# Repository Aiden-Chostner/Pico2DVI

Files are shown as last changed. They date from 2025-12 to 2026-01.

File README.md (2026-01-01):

# Pico2DVI
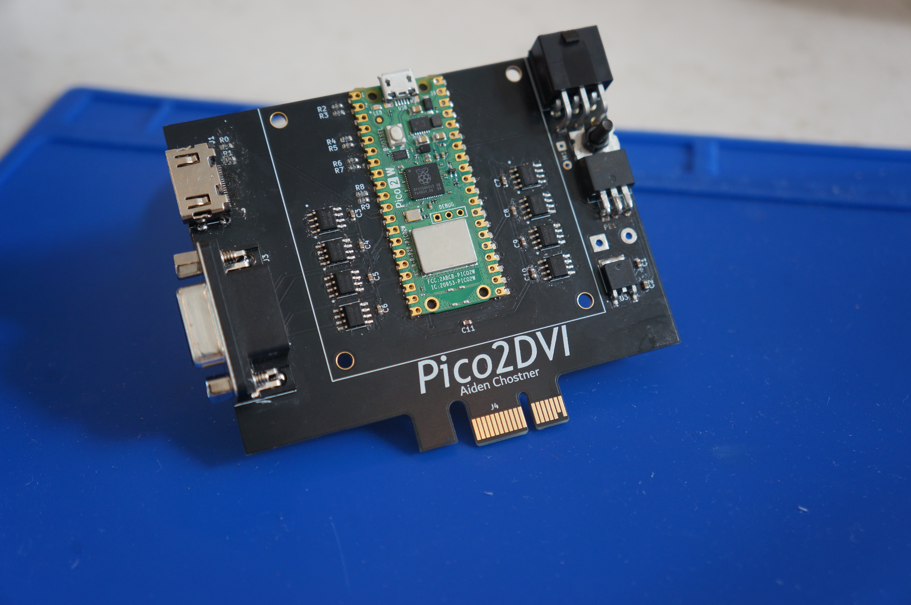
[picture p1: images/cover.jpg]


## Story
Recently, I began exploring circuit design, and I liked the idea of creating my own custom graphics card because it sounded like a fun project. After some back and forth of choosing requirements for the GPU, I settled on using a Raspberry Pi Pico as the main processor. It already had a graphics library made for it, which would make adding HDMI support simple. I saw [PicoDVI by Luke Wren](https://github.com/Wren6991/PicoDVI), but I wanted to add more RAM and some extra capabilities. I added 32MB of VRAM (Video Random Access Memory), which is about 250 times less capacity and 36 million times slower than the memory on a modern GPU. (As you can probably tell, I was not going for speed.) The Pico also has Wi-Fi and extra general-purpose pins. That means the card can take in user inputs like a keyboard and output data in ways other than just a display. It can also fetch data (e.g stock market information) from the Internet. I prioritized versatility over speed.

## Specs
* RP2350 Core
* 32 MB VRAM
* HDMI DVI
* Extra I/O
* Subzero Cooler
* Wifi 2.4 GHz

## If you want to build it, I have an [instructables page](https://www.instructables.com/Pico2DVI-the-Graphics-Card-You-Can-Build-Yourself/)!

## Schematic
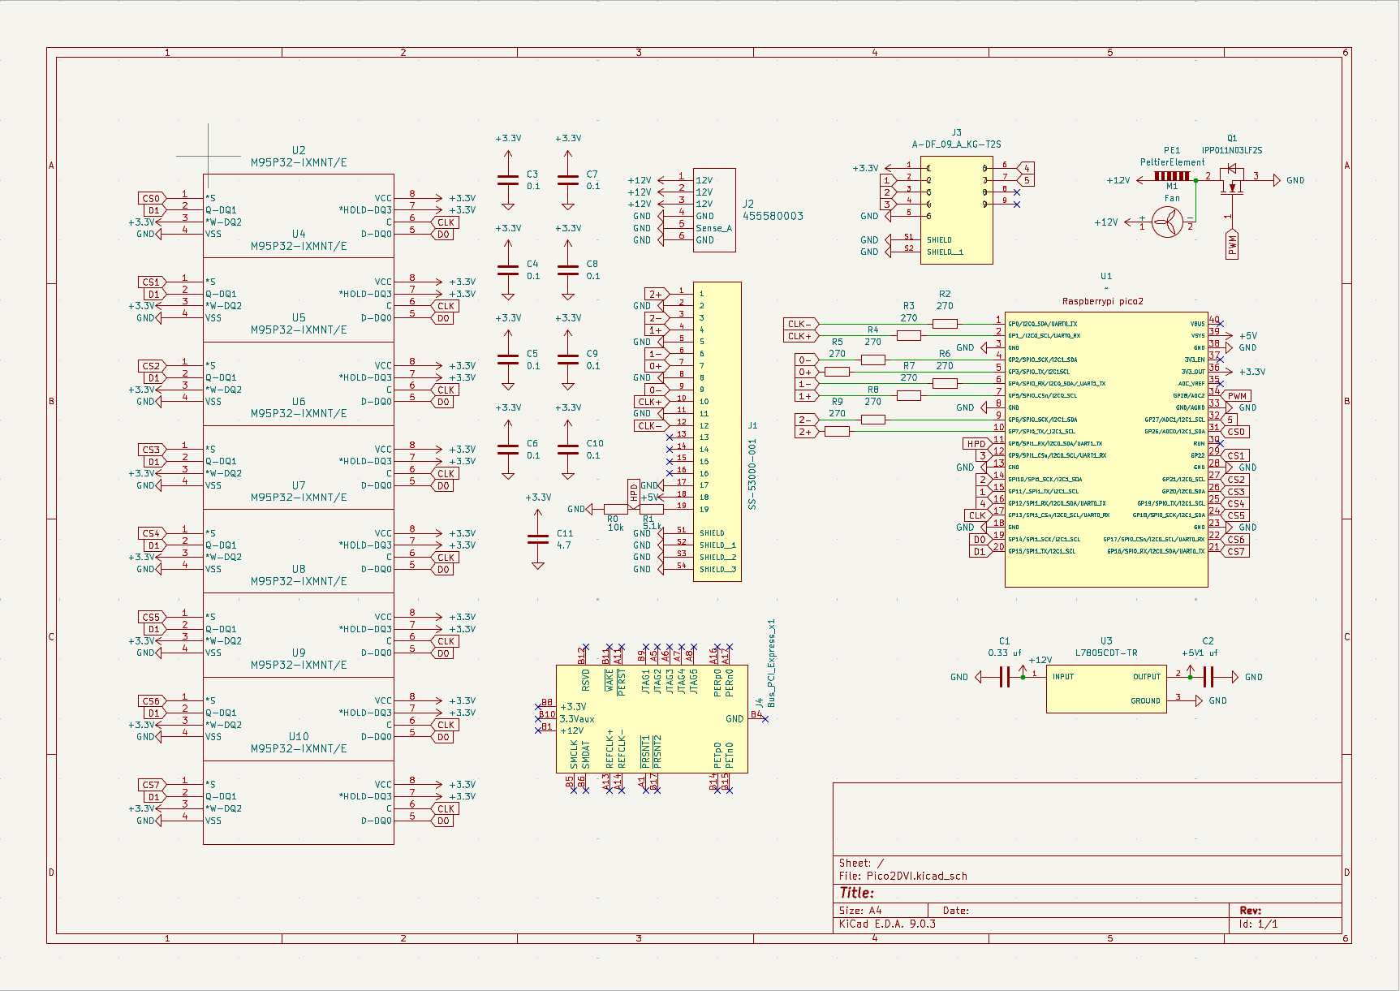
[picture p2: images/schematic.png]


### I went through a couple variations changing:
* Memory
* Cooling
* Extra I/O Pins

## PCB
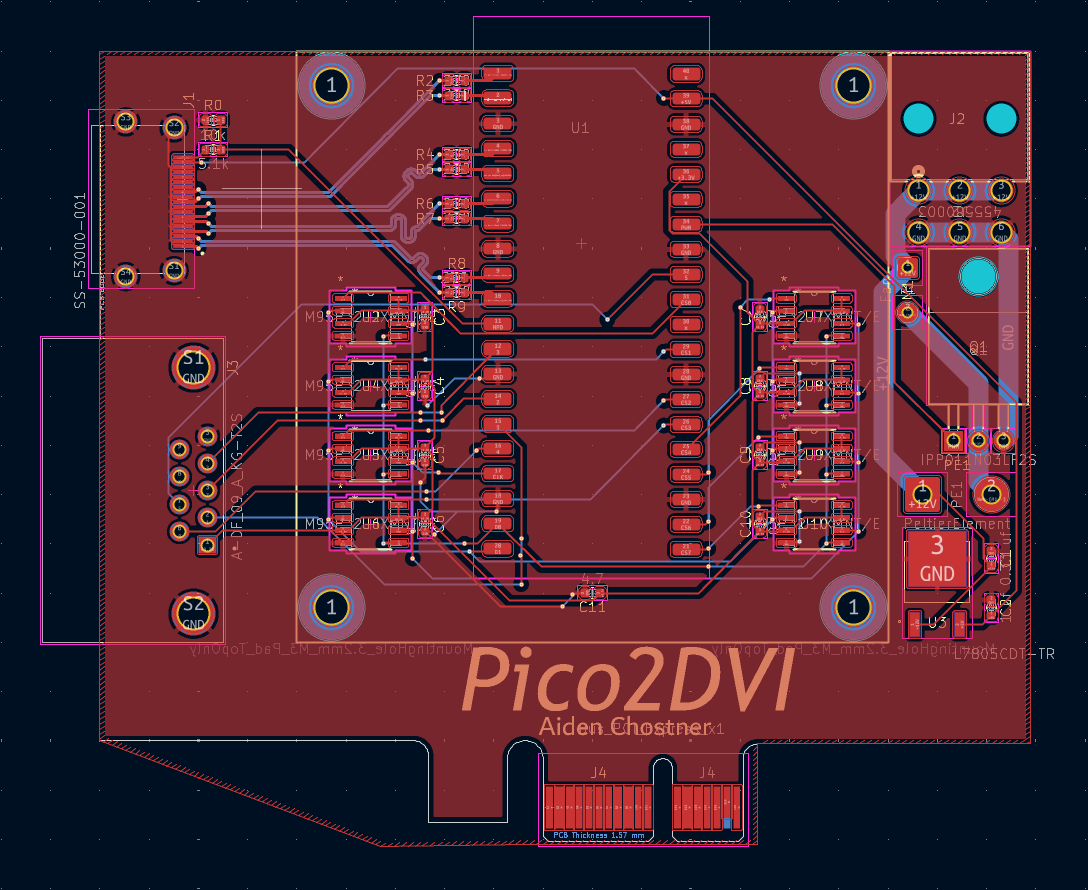
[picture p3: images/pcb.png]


### Impedance 
The hardest part about designing the PCB was getting the DVI traces correct. At the clock speeds that DVI runs at, electricity starts to behave unpredictably. The signals start to degrade to the point where they cannot be properly received by the monitor. To correct the signals, I needed to use the impedance calculator in KiCad. It took a couple of attempts through trial and error to correctly calculate the impedance needed for DVI.

## Subzero Cooler
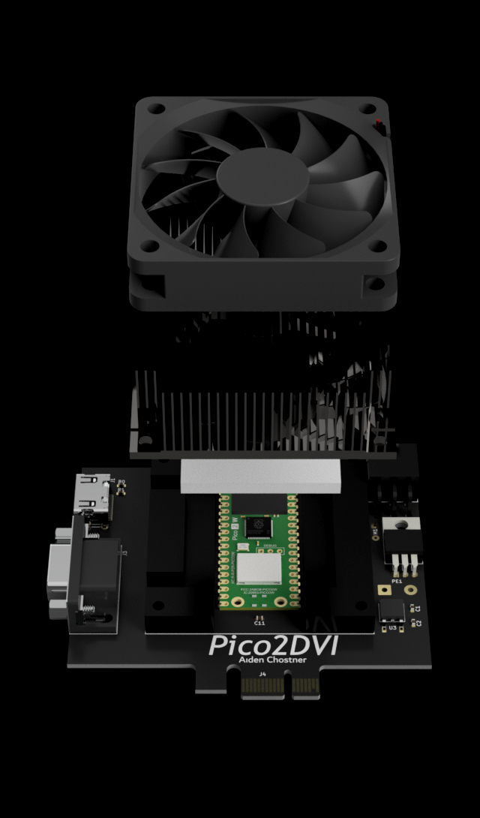
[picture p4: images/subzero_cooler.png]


### Peltier Module
For HDMI to work properly the Raspberry Pi needs to be overclocked. This generates excess heat so I designed a subzero cooler. It uses a Peltier module which uses electricity to move heat from one side to the other. Using one on the GPU allows the core temperature to be lower than the room it is in.

## Memory
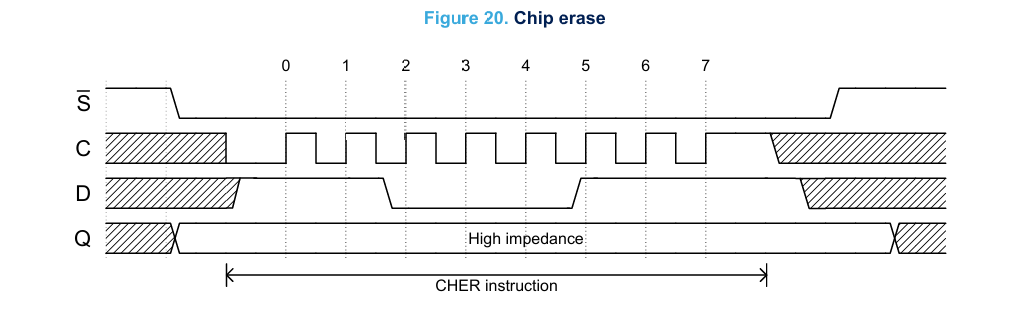
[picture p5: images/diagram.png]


### Bitbanging
The protocol the memory chips use is called SPI. (Serial Peripheral Interface) Each chip uses four wires on a shared bus with every other chip, which saves valuable GPIO pins from the Raspberry Pi. I decided to bitbang the signals and code them manually. Each instruction, like reading or writing, has a different timing diagram like the one above. I made a function that had modular instructions so I did not have to manually code each one.

# Projects!
## Hello World
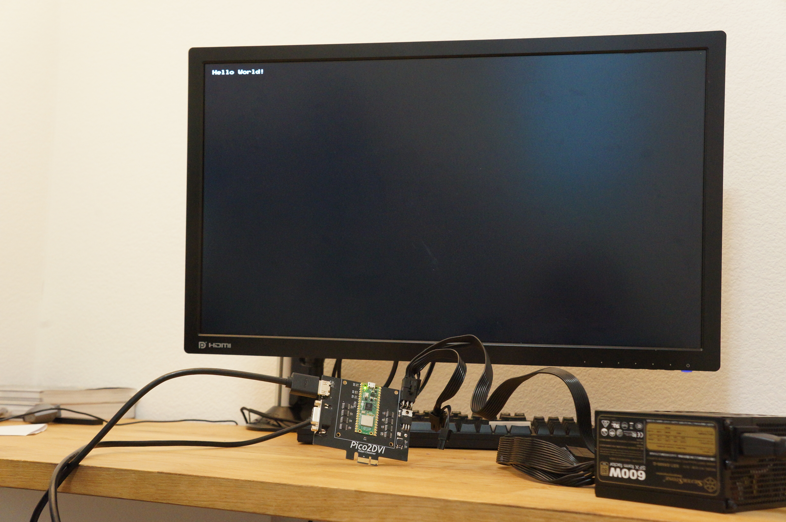
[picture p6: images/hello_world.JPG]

When I first got the graphics card working I was so excited. It took four revisions to get the circuit board design right. The months of designing and building finally paid off!

Then, I started work on making a frame to build off of. I first started to work on controlling the cooler. It uses a feedback loop so it can idle at a set temperature. It can even go below zero! Next, I added a overlay that shows all the data of the graphics card, including FPS, clock speed, and more. I also made a simple render script so that the card can display pixels instead of just plain text.

## Conway's Game of Life
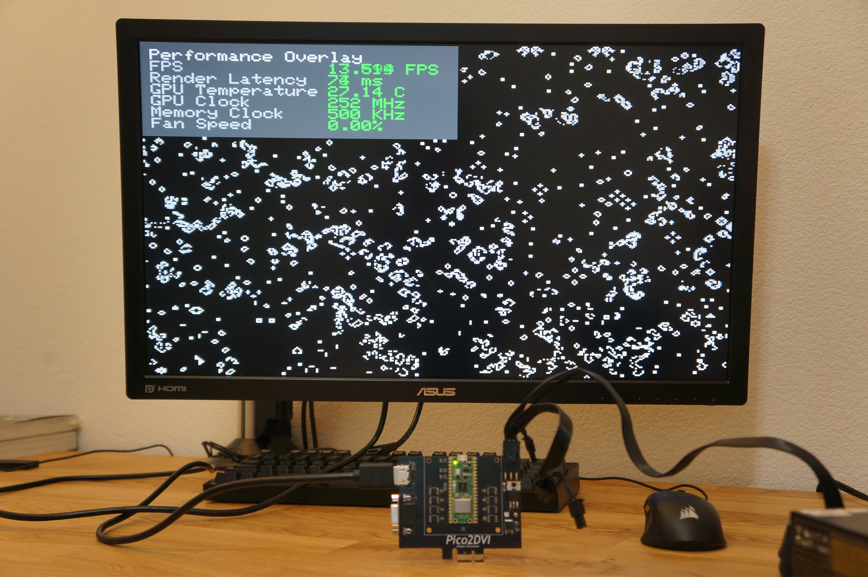
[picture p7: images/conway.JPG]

Conway's Game of Life is a zero player game where there is a grid with cells. Each cell can either be alive or dead. The eight pixels around a cell are called its neighbors. If there are less than two neighbors, that cell will die. If there are two or three neighbors around a live cell, then it will move on to the next generation. If there are more than three neighbors, it will die. If there are exactly three cells around a dead cell, it becomes alive. These four simple rules create a complex system.

To make the game, I used two screen buffers. One buffer to render to the screen and in the background, I would use the second one to calculate the next generation. Each pixel needs to know its neighbors around it, so I created an indexing system. Each pixel has its own index which I add or subtract a certain value to get the position of the pixels around it. Using the position, it checks whether or not the cell is alive.

## Future
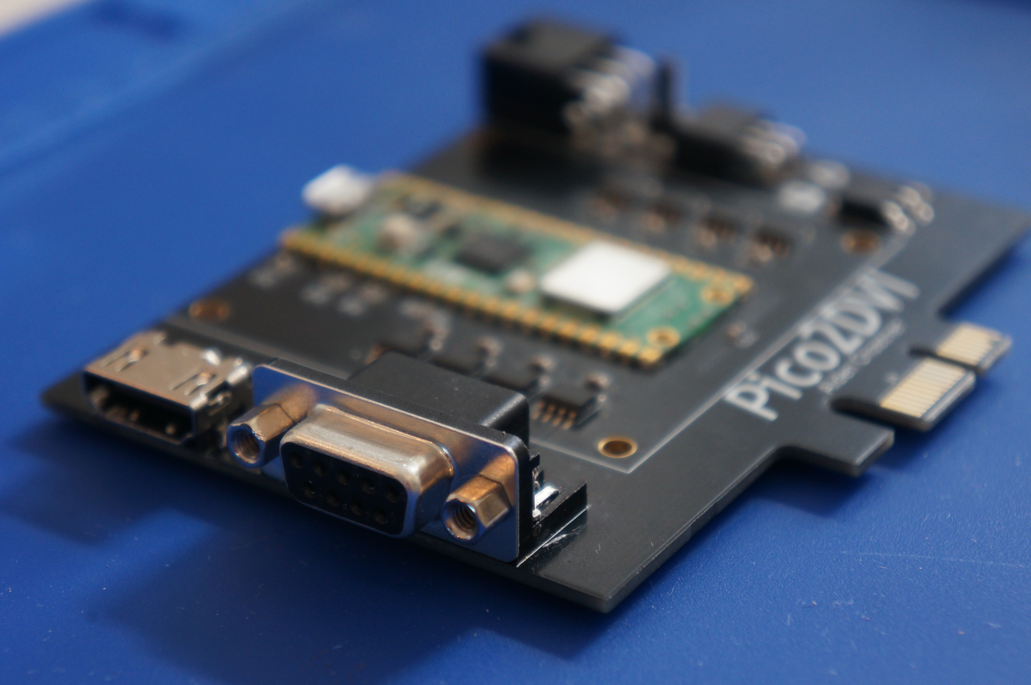
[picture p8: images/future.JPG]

In the future, I want to expand this project by making a couple games like Tetris or maybe Doom. I think a simple raytracing engine would be cool. I have tried making a simple engine in [Shadertoy](https://shadertoy.com) and it was pretty fun. I could even use the memory to make a neural network!

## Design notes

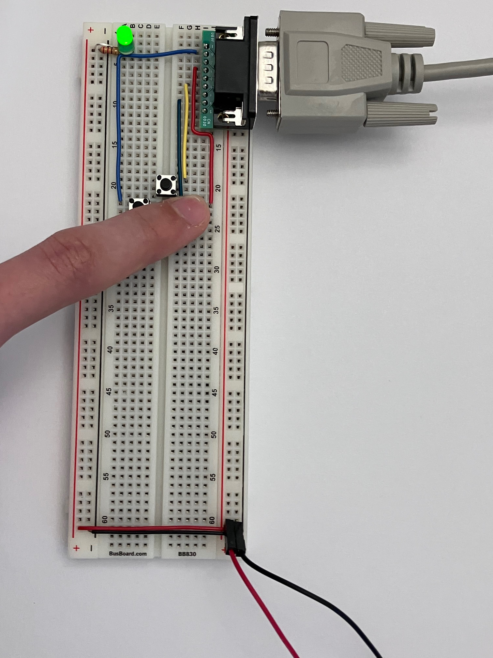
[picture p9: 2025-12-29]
images/buttons.jpg

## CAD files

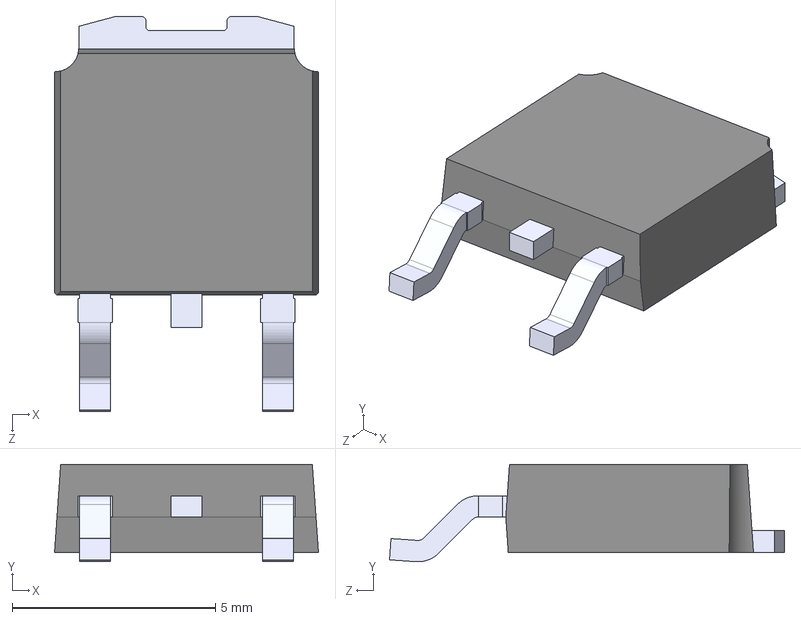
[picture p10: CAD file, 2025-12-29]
KiCad/Footprints/5V/L7805CDT-TR.step
6.50 x 2.40 x 9.72 mm

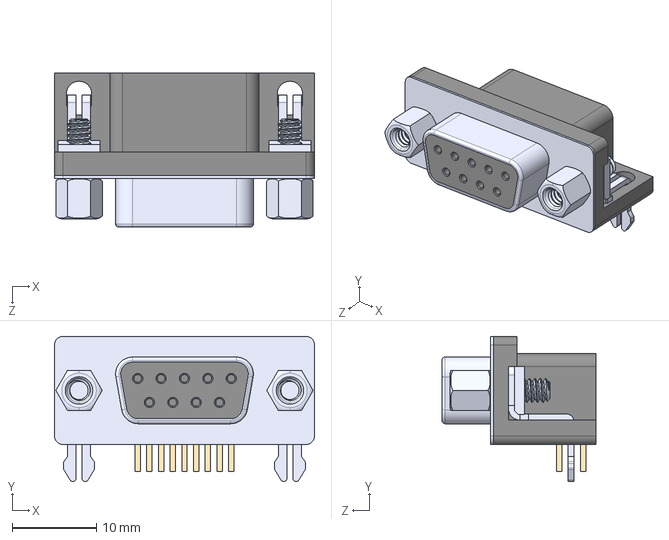
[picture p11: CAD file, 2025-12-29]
KiCad/Footprints/Dsub 9/A-DF_09_A_KG-T2S.step
30.8 x 17.2 x 18.3 mm

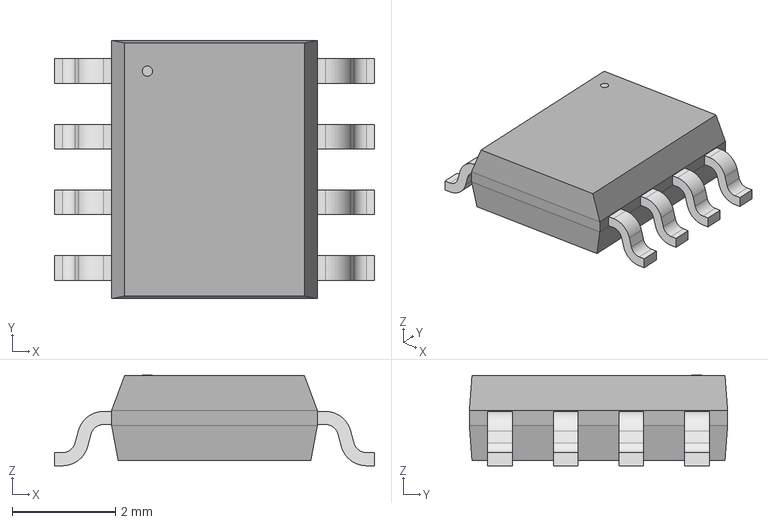
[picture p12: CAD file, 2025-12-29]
KiCad/Footprints/Eeprom/SO8N_4X5X1P27_STM.step
6.20 x 5.00 x 1.75 mm

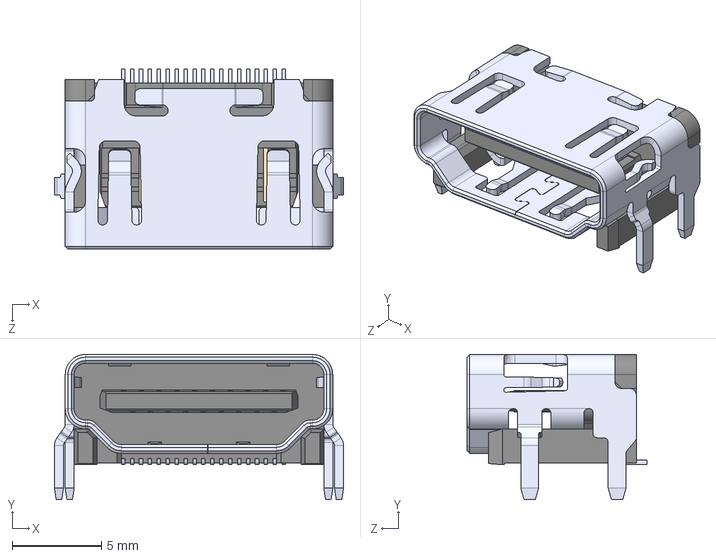
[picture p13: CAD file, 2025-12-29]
KiCad/Footprints/HDMI/SS-53000-001.step
16.2 x 8.13 x 10.1 mm

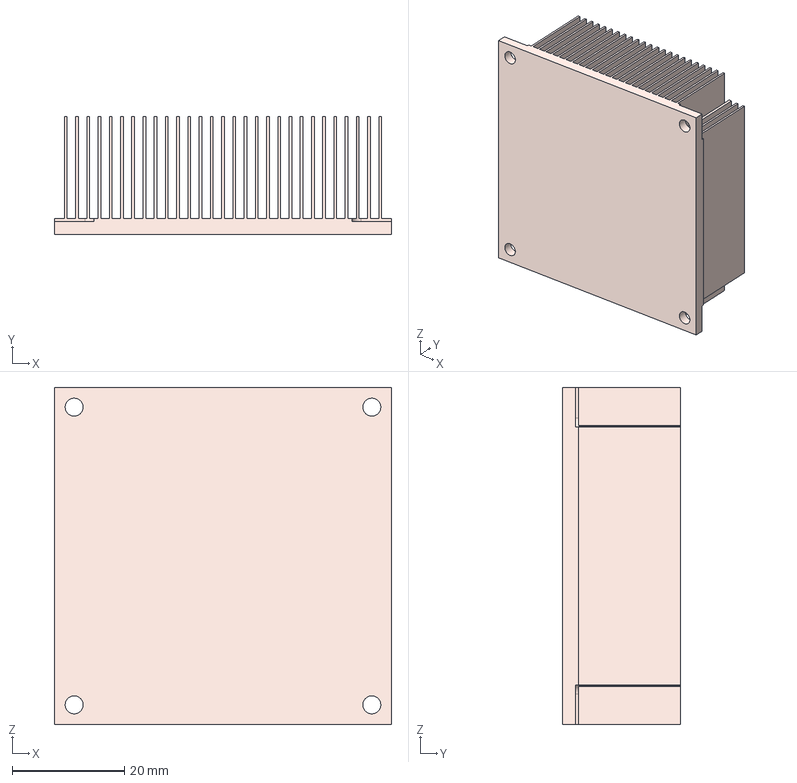
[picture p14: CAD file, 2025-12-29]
Models/Heatsink.step
60.0 x 21.0 x 60.0 mm

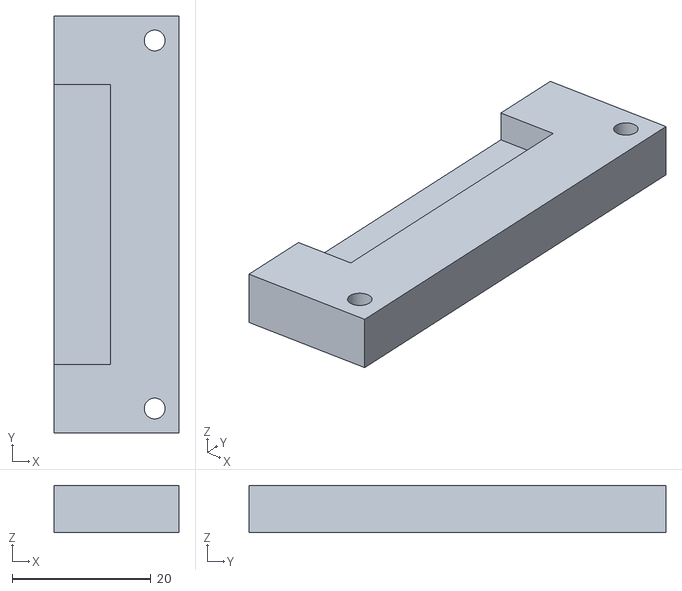
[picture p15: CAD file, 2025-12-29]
production/3D Printed/Mount R.stl
18.0 x 60.0 x 6.83

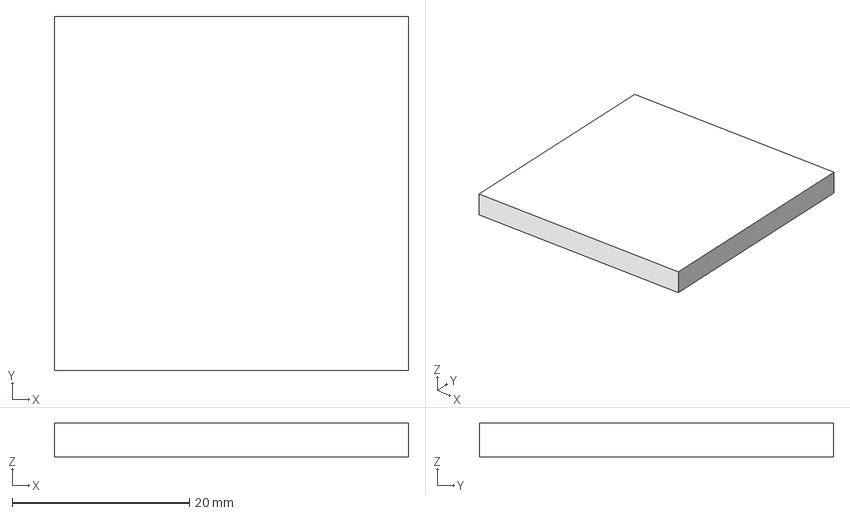
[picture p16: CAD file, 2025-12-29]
Models/Peltier.step
40.0 x 40.0 x 3.80 mm

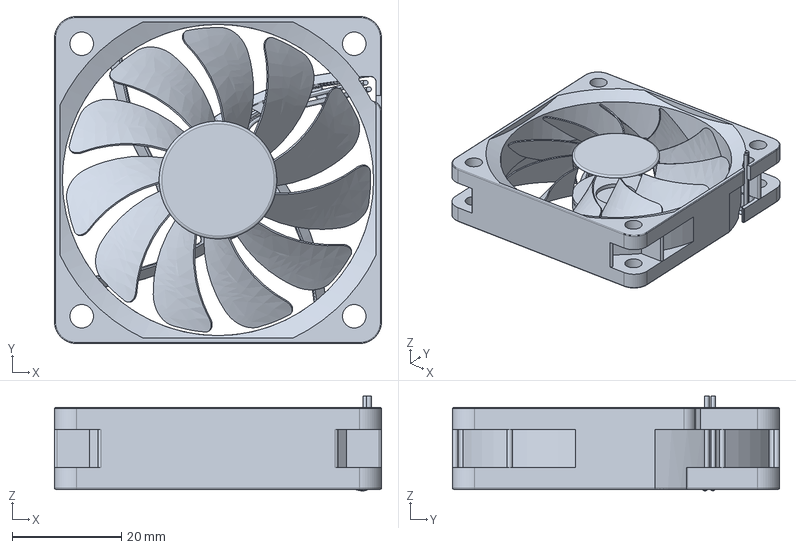
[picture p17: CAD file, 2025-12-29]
Models/Fan.step
60.0 x 60.0 x 17.4 mm

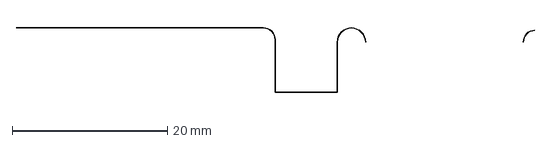
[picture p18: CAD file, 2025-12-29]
Models/PCIE Template.dxf
66.8 x 8.25 mm

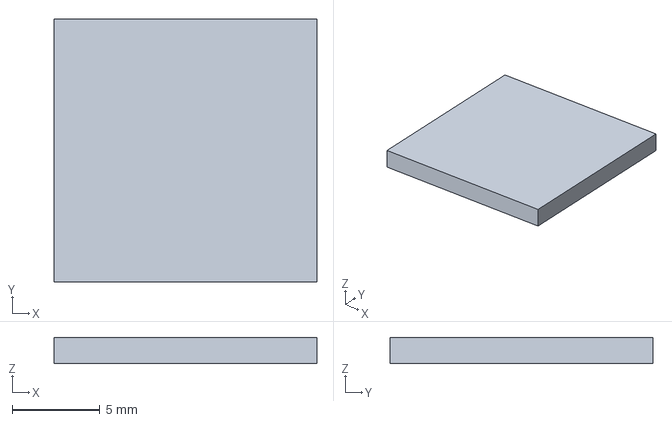
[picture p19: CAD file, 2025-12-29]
Models/Themal Pad.step
15.0 x 15.0 x 1.50 mm

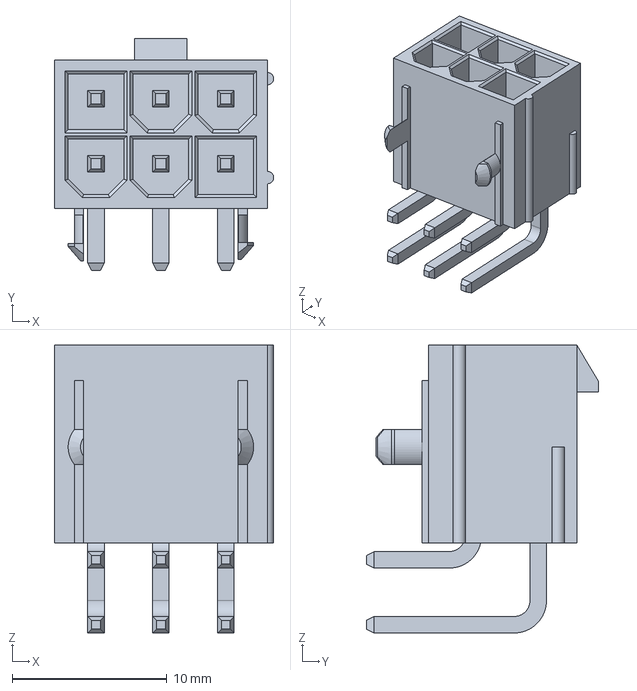
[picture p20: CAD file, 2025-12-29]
KiCad/Footprints/Molex/455580003.stp
14.2 x 15.0 x 18.6 mm

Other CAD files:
production/3D Printed/Mount L.stl

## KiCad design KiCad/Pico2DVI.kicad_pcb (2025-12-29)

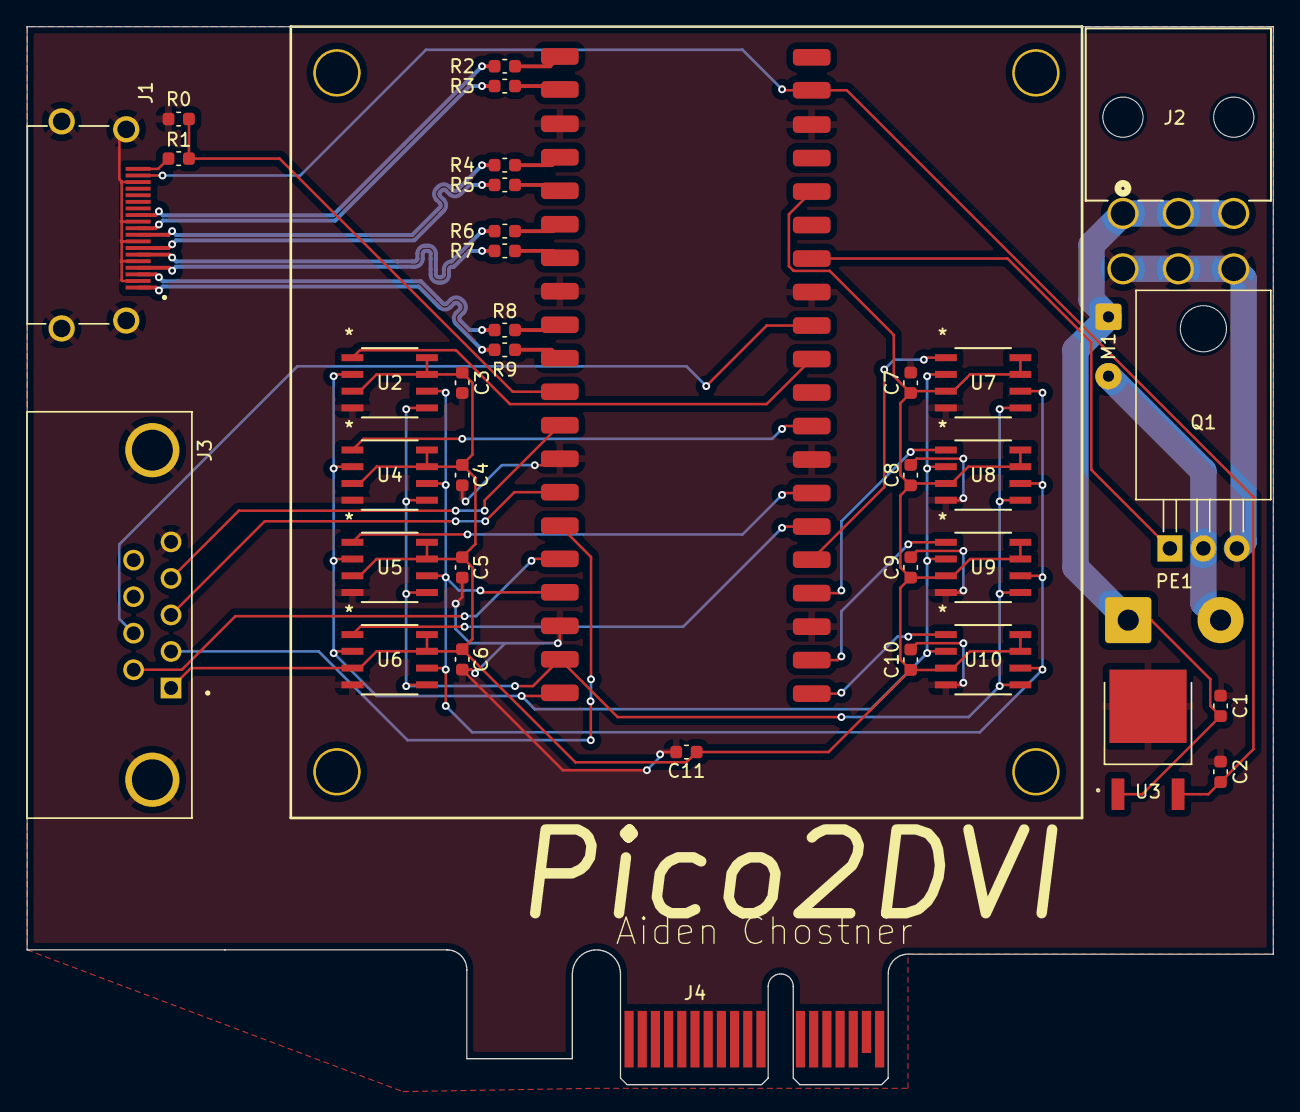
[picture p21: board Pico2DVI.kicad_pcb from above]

Board: 2 copper layers, 94.5 x 80.2 mm, 38 parts (0 on the bottom side), 40 nets.

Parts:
C1: 0.33 uf; C_0603_1608Metric
C2: 1 uf; C_0603_1608Metric
C3, C4, C5, C6, C7, C8, C9, C10: 0.1; C_0603_1608Metric
C11: 4.7; C_0603_1608Metric
J1: SS-53000-001; STEWART_SS-53000-001
J2: 455580003; CONN_SD-45558-001_MOL
J3: A-DF_09_A_KG-T2S; ASSMANN_A-DF_09_A_KG-T2S
J4: Bus_PCI_Express_x1; BUS_PCIexpress_x1
M1: Fan; SolderWire-0.25sqmm_1x02_P4.5mm_D0.65mm_OD2mm
PE1: PeltierElement; SolderWire-0.75sqmm_1x02_P7mm_D1.25mm_OD3.5mm
Q1: IPP011N03LF2S; TO-220-3_Horizontal_TabDown
R0: 10k; C_0603_1608Metric
R1: 5.1k; C_0603_1608Metric
R2, R3, R4, R5, R6, R7, R8, R9: 270; C_0603_1608Metric
U1: Raspberrypi pico2 w SMD
U2, U4, U5, U6, U7, U8, U9, U10: M95P32-IXMNT/E; SO8N_4X5X1P27_STM-M
U3: L7805CDT-TR; VREG_L7805CDT-TR

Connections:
0+: J1.7, R5.1
0-: J1.9, R4.1
1: J3.2, U1.15 (GP11/_SPI1_TX/I2C1_SCL)
1+: J1.4, R7.1
1-: J1.6, R6.1
2: J3.3, U1.14 (GPI10/SPI1_SCK/I2C1_SDA)
2+: J1.1, R9.1
2-: J1.3, R8.1
3: J3.4, U1.12 (GP9/SPI1_CSn/I2C0_SCL/UART1_RX)
4: J3.6, U1.16 (GP12/SPI1_RX/I2C0_SDA/UART0_TX)
5: J3.7, U1.32 (GP27/ADC1/I2C1_SCL)
+3.3V: C3.1, C4.1, C5.1, C6.1, C7.1, C8.1, C9.1, C10.1, C11.1, J3.1, U1.36 (3V3_OUT), U2.3 (*W-DQ2), U2.7 (*HOLD-DQ3), U2.8 (VCC), U4.3 (*W-DQ2), U4.7 (*HOLD-DQ3), U4.8 (VCC), U5.3 (*W-DQ2), U5.7 (*HOLD-DQ3), U5.8 (VCC), U6.3 (*W-DQ2), U6.7 (*HOLD-DQ3), U6.8 (VCC), U7.3 (*W-DQ2), U7.7 (*HOLD-DQ3), U7.8 (VCC), U8.3 (*W-DQ2), U8.7 (*HOLD-DQ3), U8.8 (VCC), U9.3 (*W-DQ2), U9.7 (*HOLD-DQ3), U9.8 (VCC), U10.3 (*W-DQ2), U10.7 (*HOLD-DQ3), U10.8 (VCC)
+5V: C2.1, J1.18, U1.39 (VSYS), U3.2 (OUTPUT)
+12V: C1.1, J2.1 (12V), J2.2 (12V), J2.3 (12V), M1.1 (+), PE1.1, U3.1 (INPUT)
CLK: U1.17 (GP13/SPI1_CSn/I2C0_SCL/UART0_RX), U2.6 (C), U4.6 (C), U5.6 (C), U6.6 (C), U7.6 (C), U8.6 (C), U9.6 (C), U10.6 (C)
CLK+: J1.10, R3.1
CLK-: J1.12, R2.1
CS0: U1.31 (GP26/ADC0/I2C1_SDA), U2.1 (*S)
CS1: U1.29 (GP22), U4.1 (*S)
CS2: U1.27 (GP21/I2C0_SCL), U5.1 (*S)
CS3: U1.26 (GP20/I2C0_SDA), U6.1 (*S)
CS4: U1.25 (GP19/SPI0_TX/I2C1_SCL), U7.1 (*S)
CS5: U1.24 (GP18/SPI0_SCK/I2C1_SDA), U8.1 (*S)
CS6: U1.22 (GP17/SPI0_CSn/I2C0_SCL/UART0_RX), U9.1 (*S)
CS7: U1.21 (GP16/SPI0_RX/I2C0_SDA/UART0_TX), U10.1 (*S)
D0: U1.19 (GP14/SPI1_SCK/I2C1_SCL), U2.5 (D-DQ0), U4.5 (D-DQ0), U5.5 (D-DQ0), U6.5 (D-DQ0), U7.5 (D-DQ0), U8.5 (D-DQ0), U9.5 (D-DQ0), U10.5 (D-DQ0)
D1: U1.20 (GP15/SPI1_TX/I2C1_SCL), U2.2 (Q-DQ1), U4.2 (Q-DQ1), U5.2 (Q-DQ1), U6.2 (Q-DQ1), U7.2 (Q-DQ1), U8.2 (Q-DQ1), U9.2 (Q-DQ1), U10.2 (Q-DQ1)
GND: C1.2, C2.2, C3.2, C4.2, C5.2, C6.2, C7.2, C8.2, C9.2, C10.2, C11.2, J1.2, J1.5, J1.8, J1.11, J1.17, J1.S1 (SHIELD), J1.S2 (SHIELD__1), J1.S3 (SHIELD__2), J1.S4 (SHIELD__3), J2.4 (GND), J2.5 (Sense_A), J2.6 (GND), J3.5, J3.S1 (SHIELD), J3.S2 (SHIELD__1), Q1.3 (SOURCE), R0.2, U1.3 (GND), U1.8 (GND), U1.13 (GND), U1.18 (GND), U1.23 (GND), U1.28 (GND), U1.33 (GND/AGND), U1.38 (GND), U2.4 (VSS), U3.3 (GROUND), U4.4 (VSS), U5.4 (VSS), U6.4 (VSS), U7.4 (VSS), U8.4 (VSS), U9.4 (VSS), U10.4 (VSS)
HPD: R0.1, R1.2, U1.11 (GP8/SPI1_RX/I2C0_SDA/UART1_TX)
unnamed: J1.19, R1.1
unnamed: M1.2 (-), PE1.2, Q1.2 (DRAIN)
unnamed: R2.2, U1.1 (GP0/I2C0_SDA/UART0_TX)
unnamed: R3.2, U1.2 (GP1_/I2C0_SCL/UART0_RX)
unnamed: R4.2, U1.4 (GP2/SPIO_SCK/I2C1_SDA)
unnamed: R5.2, U1.5 (GP3/SPIO_TX/I2C1SCL)
unnamed: R6.2, U1.6 (GP4/SPIO_RX/I2C0_SDA/_UART1_TX)
unnamed: R7.2, U1.7 (GP5/SPIO_CSn/I2C0_SCL)
unnamed: R8.2, U1.9 (GP6/SPIO_SCK/I2C1_SDA)
unnamed: R9.2, U1.10 (GP7/SPI0_TX/_I2C1_SCL)
PWM: Q1.1 (GATE), U1.34 (GP28/ADC2)

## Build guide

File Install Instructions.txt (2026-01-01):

1.Install the Arduino IDE
2.In the IDE go to File → Preferences
3.Paste https://github.com/earlephilhower/arduino-pico/releases/download/global/package_rp2040_index.json into Additional Boards Manager
4.Go to Tools → Board → Boards Manager
5.Search for Raspberry Pi Pico/RP2040/RP2350
6.Click Install
7.Go to Tools → Manage Libraries
8.Search for PicoDVI - Adafruit Fork
9.Click install all
10.Download common_dvi_pin_configs.h
11.Paste into c:/Users/YourUsername/Documents/Arduino/libraries/PicoDVI_-_Adafruit_Fork/software/include
12.Click replace the file in the destination

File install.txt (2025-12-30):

1.Install Arduino IDE https://www.arduino.cc/en/software/
2.In IDE go to File then Preferences
3.Paste https://github.com/earlephilhower/arduino-pico/releases/download/global/package_rp2040_index.json into Additional Boards Manager
4.Go to Tools then Board then Boards Manager
5.Search for Raspberry Pi Pico/RP2040/RP2350
6.Click Install
7.Go to Tools then Manage Libraries
8.Search for PicoDVI - Adafruit Fork
9.Click install all
10.Go to Pico2DVI/Config and copy common_dvi_pin_configs.h
Paste into c:/Users/YourUsername/Documents/Arduino/libraries/PicoDVI_-_Adafruit_Fork/software/include Click Replace the File in the Destination

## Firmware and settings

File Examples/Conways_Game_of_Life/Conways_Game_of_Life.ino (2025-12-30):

#include <PicoDVI.h>
#include <Adafruit_GFX.h>
#include <cmath>

//initialize display at 16bpp 320x240 60fps
DVIGFX16 display(DVI_RES_320x240p60, Pico2DVI_cfg);

//pins
const int cooler = 28;

//extra io
const int IO1 = 11;
const int IO2 = 10;
const int IO3 = 9;
const int IO4 = 12;
const int IO5 = 27;

//random
int seed;

//memory
const int CLK = 13;
const int IN = 15;
const int OUT = 14;
const int MCS0 = 26;
const int MCS1 = 22;
const int MCS2 = 21;
const int MCS3 = 20;
const int MCS4 = 19;
const int MCS5 = 18;
const int MCS6 = 17;
const int MCS7 = 16;

//time
unsigned long gpuTime = 0;

//fps and ms
float deltaTime = 16.67;
float fps = 60;

//cooling
float temp = 30;
int targetTemp = 28;
float power = 0;
bool pwm = 0;
bool overide = 0;

//colors
const int black = 0x0000;
const int red = 0xF800;
const int green = 0x07E0;
const int blue = 0x001F;
const int yellow = 0xFFE0;
const int cyan = 0x07FF;
const int magenta = 0xF81F;
const int gray1 = 0x4208; 
const int gray2 = 0x8410;
const int gray3 = 0xC618;
const int white = 0xFFFF;

//game buffers
bool buffer0[320*240];
bool buffer1[320*240];

void setup() {
  display.begin();

  //seed for memory
  seed = get_rand_64();

  //pins
  pinMode(LED_BUILTIN, OUTPUT);
  digitalWrite(LED_BUILTIN, HIGH);
  pinMode(cooler, OUTPUT);

  //memory
  pinMode(CLK, OUTPUT);
  pinMode(IN, INPUT);
  pinMode(OUT, OUTPUT);

  pinMode(MCS0, OUTPUT);
  pinMode(MCS1, OUTPUT);
  pinMode(MCS2, OUTPUT);
  pinMode(MCS3, OUTPUT);
  pinMode(MCS4, OUTPUT);
  pinMode(MCS5, OUTPUT);
  pinMode(MCS6, OUTPUT);
  pinMode(MCS7, OUTPUT);

  digitalWrite(CLK, LOW);
  digitalWrite(OUT, LOW);

  digitalWrite(MCS0, HIGH);
  digitalWrite(MCS1, HIGH);
  digitalWrite(MCS2, HIGH);
  digitalWrite(MCS3, HIGH);
  digitalWrite(MCS4, HIGH);
  digitalWrite(MCS5, HIGH);
  digitalWrite(MCS6, HIGH);
  digitalWrite(MCS7, HIGH);

  //check memory
  bool error = 0;
  display.fillScreen(red);
  display.setTextSize(1);
  display.setTextColor(black);
  display.setCursor(5, 13);
  if (!(SPIM(MCS0, 1, 0x83, 0x000000, 0) == 0x20)||
      !(SPIM(MCS0, 1, 0x83, 0x000001, 0) == 0x00)||
      !(SPIM(MCS0, 1, 0x83, 0x000002, 0) == 0x16)||
      !(SPIM(MCS0, 1, 0x83, 0x000003, 0) == 0x00)||
      !(SPIM(MCS0, 1, 0x83, 0x000004, 0) == 0xFF)
  ) {
    display.println("CHECK ORIENTATION OF M0");
    error = 1;
  }
  
  for (int i = 0; i < 7; i++) {
    if (!(SPIM(i+16, 1, 0x83, 0x000000, 0) == 0x20)||
        !(SPIM(i+16, 1, 0x83, 0x000001, 0) == 0x00)||
        !(SPIM(i+16, 1, 0x83, 0x000002, 0) == 0x16)||
        !(SPIM(i+16, 1, 0x83, 0x000003, 0) == 0x00)||
        !(SPIM(i+16, 1, 0x83, 0x000004, 0) == 0xFF)
    ) {
    display.setCursor(5, 21+(8*i));
    display.println("CHECK ORIENTATION OF M" + String(i+1));
    error = 1;
    }
  }

  if (error == 1) {
    display.setCursor(5, 5);
    display.println("MEMORY TEST FAILED");
    while(true) {}
  } else {
    display.fillScreen(black);
    display.setTextSize(1);
    display.setTextColor(green);
    display.setCursor(5, 5);
    display.println("MEMORY TEST PASSED");
    delay(5000);
    display.fillScreen(black);
  }

  //initial burst
  digitalWrite(cooler, HIGH);
  delay(1000);
  digitalWrite(cooler, LOW);

  for (int i=0; i<240*320; i++) {
    buffer0[i] = random(0,2);
    buffer1[i] = 0;
  }
}

void loop() {
  unsigned long currentTime = millis();
  
  overide = 0;
  temp = analogReadTemp();

  //update cooling every second
  if(currentTime - gpuTime >= 1000) {
    cooling();
  }

  //cooling pwm
  if(currentTime - trunc(currentTime) <= power) {
    digitalWrite(cooler, HIGH);
  } else {
    digitalWrite(cooler, LOW);
  }

  //render
  render(currentTime);
}

void cooling() {
  //overides
  if(temp > 40) {
    power = 0;
    overide = 1; 
  }

  if(temp > 30 && temp <= 40) {
    power = 0.5;
    overide = 1;
  }
  
  if(temp <= -0.25) {
    power = 0.75;
    overide = 1;
  }

  if(temp < targetTemp && overide == 0) {
    power = 0;
    overide = 1;
  }

  //fan speed brackets based on target temperature
  if(overide == 0) {
    if(targetTemp <= 30 && targetTemp >= 27) power = 0.2;
    else if(targetTemp < 27 && targetTemp >= 24) power = 0.3;
    else if(targetTemp < 24 && targetTemp >= 17) power = 0.4;
    else if(targetTemp < 17 && targetTemp >= 14) power = 0.5;
    else if(targetTemp < 14 && targetTemp >= 11) power = 0.6;
    else if(targetTemp < 11 && targetTemp >= 8) power = 0.7;
    else if(targetTemp < 8 && targetTemp >= 5) power = 0.8;
    else if(targetTemp < 5 && targetTemp >= 4) power = 0.9;
    else if(targetTemp < 4) power = 1;
  }
}

void render(unsigned long currentTime) {
  for (int y = 0; y < display.height(); y++) {
    for (int x = 0; x < display.width(); x++) {
      if (!(x < 170 && y < 66)) { //draw every pixel except on overlay to prevent flickering
        int index = y*320+x;

        //game calculation
        int neighbors = buffer0[index-321] + buffer0[index-320] + buffer0[index-319] + buffer0[index-1] + buffer0[index+1] + buffer0[index+319] + buffer0[index+320] + buffer0[index+321];
        if (neighbors<=1 || neighbors>=4) {
          buffer1[index] = 0;
        }
        if(neighbors>=2 && neighbors <=3 && buffer0[index]==1) {
          buffer1[index] = 1;
        }
        if(neighbors==3 && buffer0[index]==0) {
          buffer1[index] = 1;
        }
        display.drawPixel(x, y, buffer0[index]*65535);
      }
    }
  }
  
  //swap screen buffer to secondary
  for (int i=0; i<240*320; i++) {
    buffer0[i] = buffer1[i];
  }
  delay(50);
  overlay(currentTime);
}

void overlay (unsigned long currentTime) {
  //fps and ms
  deltaTime = millis() - currentTime;
  fps = 1000/deltaTime;

  //overlay box
  display.setTextSize(1);
  display.fillRect(0, 0, 170, 66, gray1);

  //title
  display.setTextColor(white);
  display.setCursor(5, 5);
  display.println("Performance Overlay");

  //stats
  display.setTextColor(gray3);
  display.setCursor(5, 13); display.println("FPS");
  display.setCursor(5, 21); display.println("Render Latency");
  display.setCursor(5, 29); display.println("GPU Temperature");
  display.setCursor(5, 37); display.println("GPU Clock");
  display.setCursor(5, 45); display.println("Memory Clock");
  display.setCursor(5, 53); display.println("Fan Speed");
  
  //numbers
  display.setTextColor(green);
  display.setCursor(100, 13); display.println(String(fps, 3) + " FPS");
  display.setCursor(100, 21); display.println(String(deltaTime, 0) + " ms");
  display.setCursor(100, 29); display.println(String(temp) + " C");
  display.setCursor(100, 37); display.println(String(rp2040.f_cpu()/1000000) + " MHz");
  display.setCursor(100, 45); display.println("500 KHz");
  display.setCursor(100, 53); display.println(String(power*100) + "%");
}

int SPIM(int chip, int type, int instruction, uint32_t address, int data) {

  //chip enable
  digitalWrite(chip, LOW);

  //instruction
  for (int i = 0; i < 8; i++) {
    digitalWrite(OUT, (instruction >> 7-i) & 1);
    digitalWrite(CLK, HIGH);
    delayMicroseconds(1);
    digitalWrite(CLK, LOW);
    delayMicroseconds(1);
  }
  
  //address
  if(type == 1 || type == 2 || type == 3) {
    for (int i = 0; i < 24; i++) {
      digitalWrite(OUT, (address >> 23-i) & 1);
      digitalWrite(CLK, HIGH);
      delayMicroseconds(1);
      digitalWrite(CLK, LOW);
      delayMicroseconds(1);
    }
  }

  //exit for instruction or erase
  if(type == 0 || type == 3) {
    digitalWrite(chip, HIGH);
  }

  //read
  if (type == 1) {
    data = 0;

    for (int i = 0; i < 8; i++) {
      data = data + digitalRead(IN)*pow(2, 7-i);
      digitalWrite(CLK, HIGH);
      delayMicroseconds(1);
      digitalWrite(CLK, LOW);
      delayMicroseconds(1);
    }
    digitalWrite(chip, HIGH);
    return(data);
  }

  //write
  if (type == 2) {
    for (int i = 0; i < 8; i++) {
      digitalWrite(OUT, (data >> 7-i) & 1);
      digitalWrite(CLK, HIGH);
      delayMicroseconds(1);
      digitalWrite(CLK, LOW);
      delayMicroseconds(1);
    }
    digitalWrite(chip, HIGH);
  }

  return(0);
}

//randomize memory access
int chipRandom (int c) {
  randomSeed(seed*(c+1));
  c = random(0, 8);
  if(c == 7) {
    return(26);
  } else {
    return(c+16);
  }
}

int addressRandom (int a) {
  randomSeed(seed*(a+1));
  return(random(0x000000, 0x400000));
}

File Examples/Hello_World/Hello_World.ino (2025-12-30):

#include <PicoDVI.h>
#include <Adafruit_GFX.h>

//initialize display at 1bpp 640x480 60 fps no double buffer
DVIGFX1 display(DVI_RES_640x480p60, false, Pico2DVI_cfg);

void setup() {
  display.begin();
  display.fillScreen(0);
  display.setTextColor(1);
  display.setTextSize(1);
  display.setCursor(10, 10);
  display.print("Hello World!");

  pinMode(LED_BUILTIN, OUTPUT);
  pinMode(28, OUTPUT);
}

void loop() {
  //flash led
  digitalWrite(LED_BUILTIN, HIGH);
  delay(2000);
  digitalWrite(LED_BUILTIN, LOW);
  digitalWrite(28, LOW);
  delay(2000);
}

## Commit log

2025-12-29 Update and rename Mount L.stl to production/3D Printed/Mount L.stl
    [Mount L.stl]
2025-12-29 Update and rename Mount R.stl to production/3D Printed/Mount R.stl
    [Mount R.stl]
2025-12-29 Update and rename sym-lib-table to KiCad/sym-lib-table
2025-12-29 Update and rename Raspberrypi pico2 W.kicad_sym to Symbols/Raspberrypi pico2 W.kicad_sym
2025-12-29 Update and rename Symbols/2025-08-22_21-11-44.kicad_sym to production/Symbols/2025-08-22_21-11-44.kicad_sym
2025-12-29 Update and rename 2025-08-22_21-11-44.kicad_sym to 2025-08-22_21-11-44.kicad_sym
